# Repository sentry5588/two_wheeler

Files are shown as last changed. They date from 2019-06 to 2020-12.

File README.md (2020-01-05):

# Why Another Self-Balancing Robot?
Building a physical platform to test and compare various control and estimation algorithms. Almost all existing self-balancing robot uses PID control. I plan to use other control schemes with different robot state estimation methods.

# External Libs
LinkedList - Used for debug code communication
https://github.com/ivanseidel/LinkedList

ArduinoTimer - Used for timer interrupt
https://github.com/carlosrafaelgn/ArduinoTimer

# Note
I decided to use ROS on Raspberry PI instead of Arduino for the robot.

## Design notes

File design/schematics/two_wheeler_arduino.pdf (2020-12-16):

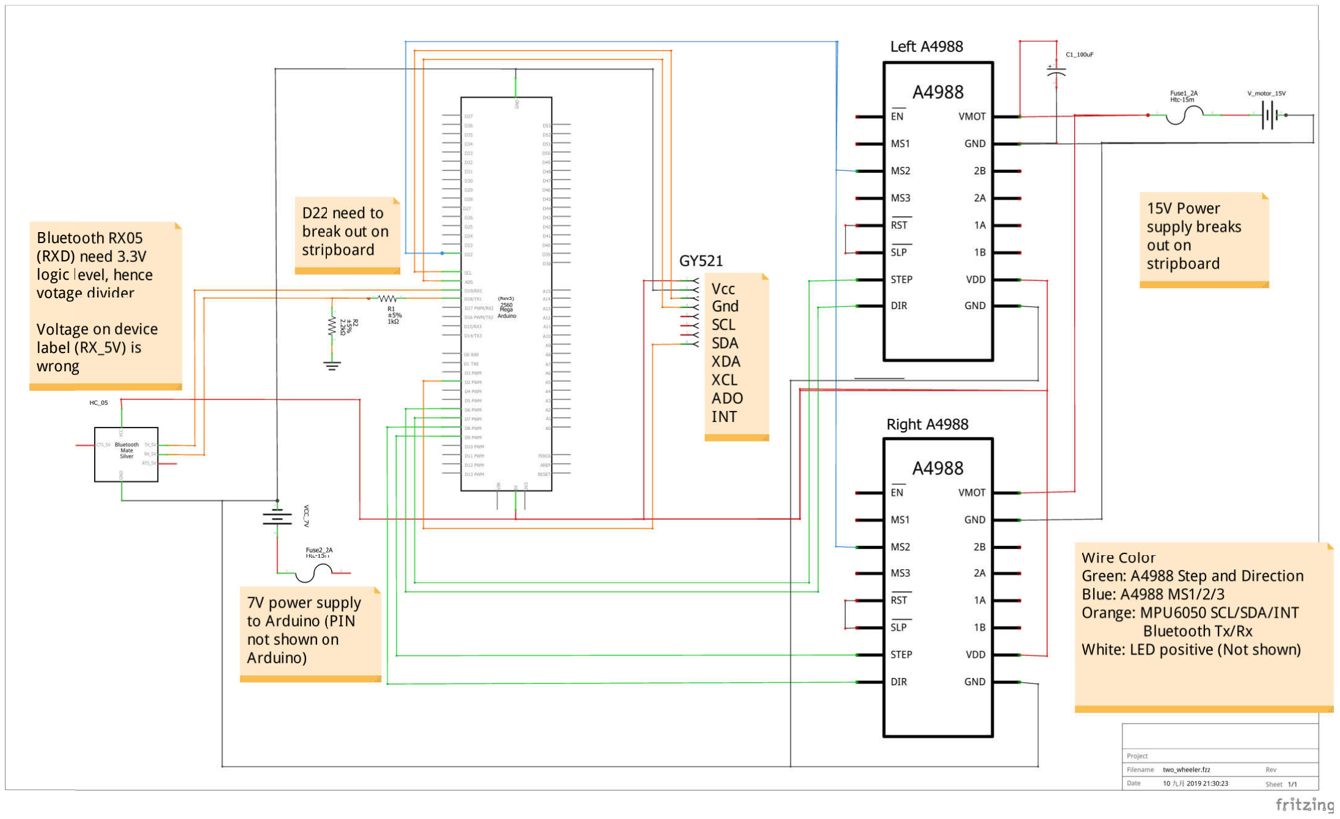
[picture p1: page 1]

Bluetooth RX05
(RXD) need 3.3V
logic level, hence
votage divider

Voltage on device
label (RX_5V) is
wrong

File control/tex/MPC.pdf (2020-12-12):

# Model Predictive Control

### sentry5588, MIT License

2020

## 1 Introduction

This note documents the Model Predictive Control (MPC) method for the two wheel balancing robot. Many people has built similar self-balancing robots. Almost all of them uses PID control as the control strategy. For position estimation, some uses Kalman filters, and others uses complementary filters. The purpose of using MPC in this robot is not trying to invent a new MPC technique, which usually the case for research papers. But rather I intend to 1) practice MPC and 2) test how well MPC behaves compares to other control schemes.

## 2 Robot Coordinates

As shown in Figure 1a, θk and ωk denotes the angular position at time step k, respectively. Counter-clockwise rotation is positive. Angular acceleration is denoted by ω˙ k. uk is the horizontal force with positive to the right. Robot specifications can be found in Table 1

## 3 Problem Formulation

The model is a 1-input-2-output model.

xk+1 = f(xk, uk) | (1)
yk = C(xk)xk | (2)

xk = [θk ωk ω˙ k]

T
is the system state. Linearize Equ 1, we have
xk+1 = A(xk)xk + B(xk)uk | (3)
yk = C(xk)xk | (4)
Specification | Notation | Value
Center of Gravity (CoG) | h | ?? 0.2 m
Mass | m | ?? 1.1 kg
Moment of Inertia | I | ?? 0.8 kg · m²

Table 1: Robot specification

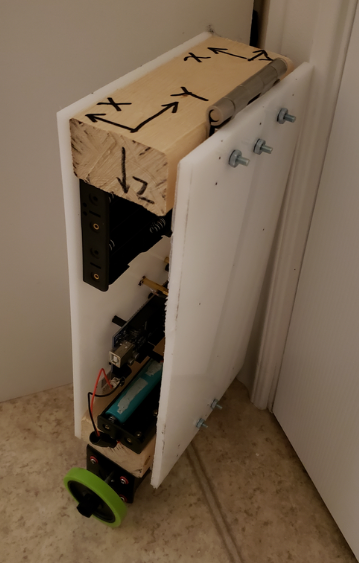
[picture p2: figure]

(a) Robot Coordinates

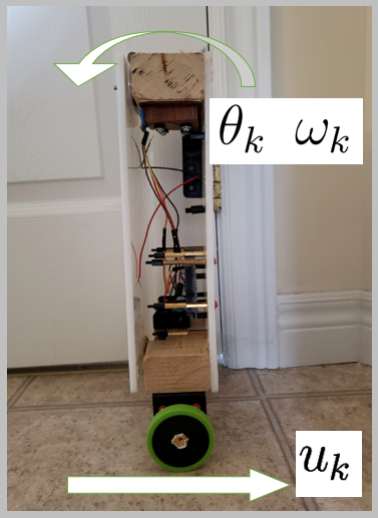
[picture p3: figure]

(b) 1D Rotation

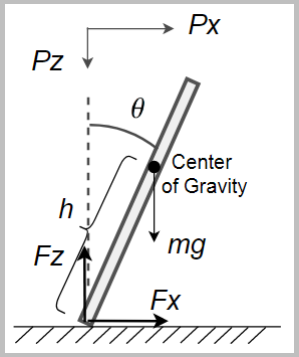
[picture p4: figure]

(c) 1D Free Dody Diagram

Figure 1: Two Wheel Balancing Robot

where A(xk) and B(xk) are Jacobians and given by

A(xk) = ∂f
∂xk

, B(xk) = ∂f
∂uk

(5)

Figure 1c is the 1-D free body diagram. In the next subsection, I will develop the nonlinear continuous-time dynamics.

### 3.1 Nonlinear Continuous-Time Model

### 3.1.1 Derived from Newton’s 2nd law

Summing the forces in figure 1c in the horizontal direction we have

Fx = mp¨x | (6)

where px is the horizontal velocity of the CoG. Summing the forces in figure 1c in the vertical direction we have

mg − Fz = mp¨z | (7)

where px is the horizontal velocity of the CoG. Summing the torques in figure 1c around the center of gravity we have

Fxh cos(θ) + Fzh sin(θ) + mg · 0 = ¨θI | (8)

The contact point between the robot and the ground has 0 vertical velocity. It’s vertical velocity is a combination of the rod rotation around CoG, ˙θh sin(θ), and vertical velocity of CoG, p˙z. Therefore

− ˙θh sin(θ) + ˙pz = 0 | (9)

Take time derivative of (9)

−¨θh sin(θ) − ˙θ
2h cos(θ) + ¨pz = 0 | (10)

p¨z = ¨θh sin(θ) + ˙θ
2h cos(θ) | (11)

Substitute p¨z in (7) with (11)

mg − Fz = m(

¨θh sin(θ) + ˙θ
2h cos(θ)) | (12)

mg − Fz = m¨θh sin(θ) + m ˙θ
2h cos(θ) | (13)

Fz = mg − m¨θh sin(θ) − m ˙θ
2h cos(θ) | (14)

Substitute Fz with above equation in (8)

Fxh cos(θ) + (mg − m¨θh sin(θ) − m ˙θ

2h cos(θ))h sin(θ) + mg · 0 = ¨θI | (15)

Fxh cos(θ) + mgh sin(θ) − m¨θh² sin²

(θ) − m ˙θ
2h

2

cos(θ) sin(θ) = ¨θI | (16)

(I + mh²

sin²

(θ))¨θ + mh²
cos(θ) sin(θ)

˙θ
2 = Fxh cos(θ) + mgh sin(θ) | (17)

So the dynamics can be written as

Fx = mp¨x | (18)

(I + mh²

sin²

(θ))¨θ + mh²
cos(θ) sin(θ)

˙θ
2 = Fxh cos(θ) + mgh sin(θ) | (19)

Check dynamics at special points for (19)
When θ = 0, i.e. the vertical up position, (19) becomes

I

¨θ = Fxh | (20)

When θ = π/2, i.e. the horizontal position pointing to the left (assume single contact point with the ground) (19) becomes

(I + mh²
)
¨θ = mgh | (21)

When θ = −π/2, i.e. the horizontal position pointing to the right (assume single contact point with the ground) (19) becomes

(I + mh²
)
¨θ = −mgh | (22)

When θ = π/4, i.e. the horizontal position pointing to the left (assume single contact point with the ground) (19) becomes

(I +

1
2

mh²
)

¨θ +

1
2

mh² ˙θ
2 =

√
2
2

Fxh +

√
2
2
mgh | (23)

### 3.1.2 Derived from Lagrangian mechanics

The derivation follows [Peacock and Hadjiconstantinou, 2007]. The Lagrangian is L = KE − P E where KE and P E are the kinematic energy and potential energy, respectively. W is the virtual work. The equation of motion can be determined by applying Lagrange mechanics in two generalized coordinate px and θ

d
dt

(
∂L
∂p˙x

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
∂θ =

∂W
∂θ | (24)

The contact point displacement relative to the center of gravity is hθ cos(θ). Therefore the absolute velocity of the contact point is px + hθ cos(θ). The kinematic energy, potential energy and virtual work are

KE =

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
, | P E = mgh cos(θ), | W = Fx(px + hθ cos(θ)) + Fxhθ cos(θ) = Fxpx + 2Fxhθ cos(θ)
(25)

Substitute (24) with (25), in px direction we have

| d dt

(
| ∂ ∂p˙x

(
| 1
| 2 mp˙
| 2 x + | 1
| | 2 I ˙θ
| | 2
)) | (26)

−

∂
∂px

(
| 1
| 2 mp˙
| 2 x +
| 1
| 2 I ˙θ
2 − mgh cos(θ)

)
| | = ∂ ∂px Fxpx + ∂ ∂px
2Fxhθ cos(θ) | (27)
| d dt
(mp˙x + 0) − (0 + 0 − 0) =Fx + 0 | (28)
| | d dt
mp˙x =Fx | (29)
mp¨x =Fx | (30)

Substitute (24) with (25), in θ direction we have

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
| mp˙
| 2 x +
| 1
| 2 I ˙θ
2 − mgh cos(θ)

)) −
| | ∂

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
2 − mgh cos(θ)

)
(31)

=

∂
∂θFxpx +

∂
∂θ 2Fxhθ cos(θ) | (32)

d
dt

(0 + I

˙θ − 0) − (0 + 0 + mgh sin(θ)) = − 2Fxhθ sin(θ) + 2Fxh cos(θ) | (33)

(0 + I

¨θ − 0) − (0 + 0 + mgh sin(θ)) = − 2Fxhθ sin(θ) + 2Fxh cos(θ) | (34)

I

¨θ − mgh sin(θ) = − 2Fxhθ sin(θ) + 2Fxh cos(θ) | (35)

I

¨θ =2Fxh cos(θ) + mgh sin(θ) − 2Fxhθ sin(θ) | (36)

### 3.2 Model Linearization and discretization

I follow [Zhakatayev et al., 2017] to linearize and discretize the nonlinear continuous-time dynamics in [?]

## References

[Peacock and Hadjiconstantinou, 2007] Peacock, T. and Hadjiconstantinou, N. (2007). Dynamics and control i. MIT OpenCourseWare.

[Zhakatayev et al., 2017] Zhakatayev, A., Rakhim, B., Adiyatov, O., Baimyshev, A., and Varol, H. A. (2017). Successive linearization based model predictive control of variable stiffness actuated robots. In 2017 IEEE International Conference on Advanced Intelligent Mechatronics (AIM), pages 1774– 1779. IEEE.

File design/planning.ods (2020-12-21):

Task | Hrs
Create arduino code – a4988 drive | 10
Arduino code – rpi connection | 5
rpi code – arduino connection | 5
schematics | 2
arduino mouting | 4
Arduino – a4988 wiring | 1
Rpi – arduino wiring | 1
max speed | 5 | rav/s
step Hz | 4000 | Hz

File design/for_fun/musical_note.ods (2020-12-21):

Note | Freq (Hz) | Left Motor PWM Freq
1 | 262 |  | 1 | 262
1.5 | 277
2 | 294 |  | 2 | 294
2.5 | 311
3 | 330 |  | 3 | 330
4 | 349 |  | 4 | 349
4.5 | 370
5 | 392 |  | 5 | 392
5.5 | 415
6 | 440 |  | 6 | 440
6.5 | 466
7 | 494 |  | 7 | 494
1 | 523 |  | 1 | 523
1.5 | 554
2 | 587 |  | 2 | 587
2.5 | 622
3 | 659 |  | 3 | 659
4 | 698 |  | 4 | 698
4.5 | 740
5 | 784 |  | 5 | 784
5.5 | 831
6 | 880 |  | 6 | 880
6.5 | 932
7 | 988 |  | 7 | 988
1 | 1047
1.5 | 1109
2 | 1175
2.5 | 1245
3 | 1319
4 | 1397
4.5 | 1480
5 | 1568
5.5 | 1661
6 | 1760
6.5 | 1865
7 | 1976

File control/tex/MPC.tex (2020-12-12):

\documentclass[12pt]{article}
\usepackage{amsmath}
\usepackage{graphicx}
\usepackage{hyperref}
\usepackage{xcolor}
\usepackage{subcaption}
\usepackage{siunitx}

\addtolength{\oddsidemargin}{-.875in}
\addtolength{\evensidemargin}{-.875in}
\addtolength{\textwidth}{1.75in}

\addtolength{\topmargin}{-.875in}
\addtolength{\textheight}{1.75in}

\title{Model Predictive Control}
\date{2020}
\author{sentry5588, MIT License}

\begin{document}
\pagecolor{lightgray}
\maketitle
\section{Introduction}
This note documents the Model Predictive Control (MPC) method for the two
wheel balancing robot. Many people has built similar self-balancing robots.
Almost all of them uses PID control as the control strategy. For position
estimation, some uses Kalman filters, and others uses complementary filters.

The purpose of using MPC in this robot is not trying to invent a new MPC
technique, which usually the case for research papers.
But rather I intend to 1) practice MPC and 2) test how well MPC behaves
compares to other control schemes.

\section{Robot Coordinates}
As shown in Figure~\ref{fig_coordinates}, $\theta_k$ and $\omega_k$ denotes 
the angular position at time step $k$, respectively.
Counter-clockwise rotation is positive. Angular acceleration is denoted
by $\dot{\omega}_k$.
$u_k$ is the horizontal force
with positive to the right. Robot specifications can be found in 
Table~\ref{tab_robot_specification}

\begin{figure}

\begin{subfigure}{0.3\textwidth}

\caption{Robot Coordinates} \label{fig_coordinates}
\end{subfigure}
\hspace*{\fill} % separation between the subfigures
\begin{subfigure}{0.3\textwidth}
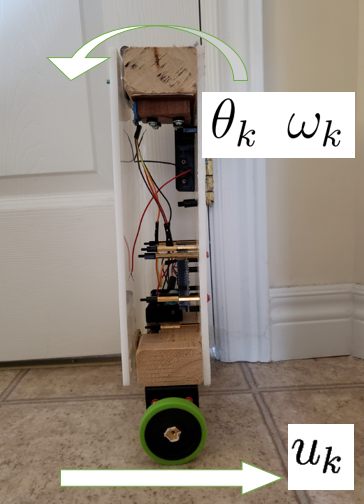
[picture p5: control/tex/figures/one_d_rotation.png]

\caption{1D Rotation} \label{fig_one_d_rotation}
\end{subfigure}
\hspace*{\fill} % separation between the subfigures
\begin{subfigure}{0.3\textwidth}
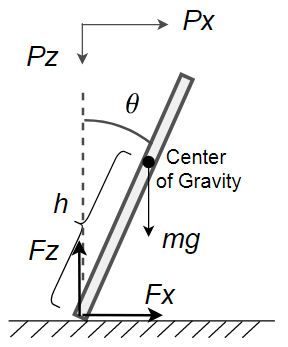
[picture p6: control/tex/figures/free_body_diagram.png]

\caption{1D Free Body Diagram} \label{fig_1d_free_body_diagram}
\end{subfigure}
\caption{Two Wheel Balancing Robot} \label{fig_robots}
\end{figure}

\begin{table}
  \centering
  \begin{tabular}{l|c|c}
    \hline
	Specification & Notation & Value \\ \hline
    Center of Gravity (CoG) & $h$ & ?? 0.2 m \\ 
	Mass & $m$ & ?? 1.1 kg \\ 
	Moment of Inertia & I & ?? 0.8 \si{\kilogram\cdot\meter^2} \\ \hline
  \end{tabular}
  \caption{Robot specification} 
  \label{tab_robot_specification}
\end{table}

\section{Problem Formulation}
The model is a 1-input-2-output model.
\begin{align}
\label{equ_orig_nonlinear_dynamics}
x_{k+1} & = f(x_k, u_k) \\
y_k & = C(x_k)x_k
\end{align}

$x_k=[\theta_k\;\;\omega_k\;\;\dot{\omega}_k]^T$ is the system state. 
Linearize Equ~\ref{equ_orig_nonlinear_dynamics}, we have
\begin{align}
x_{k+1} & = A(x_k)x_k + B(x_k)u_k \\
y_k & = C(x_k)x_k
\end{align}

where $A(x_k)$ and $B(x_k)$ are Jacobians and given by
\begin{align}
A(x_k) = \frac{\partial f}{\partial x_k},
B(x_k) = \frac{\partial f}{\partial u_k}
\end{align}

Figure~\ref{fig_1d_free_body_diagram} is the 1-D free body diagram.
In the next subsection, I will develop the nonlinear continuous-time
dynamics.

\subsection{Nonlinear Continuous-Time Model}
\subsubsection{Derived from Newton's 2nd law}
Summing the forces in figure~\ref{fig_1d_free_body_diagram} in the horizontal
direction we have
\begin{align}
F_x=m\ddot{p}_x
\end{align}
where $p_x$ is the horizontal velocity of the CoG.
Summing the forces in figure~\ref{fig_1d_free_body_diagram} in the vertical
direction we have
\begin{align}
mg-F_z = m\ddot{p}_z
\label{equ_vertical_newton}
\end{align}
where $p_x$ is the horizontal velocity of the CoG.
Summing the torques in figure~\ref{fig_1d_free_body_diagram} around the
center of gravity we have
\begin{align}
F_x h\cos(\theta) + F_z h\sin(\theta) + mg\cdot 0= \ddot{\theta}I
\label{equ_rotation_newton}
\end{align}
\textcolor{blue}{
The contact point between the robot and the ground has $0$ vertical velocity.
It's vertical velocity is a combination of the rod rotation around 
CoG, $\dot{\theta}h\sin(\theta)$,
and vertical velocity of CoG, $\dot{p}_z$. Therefore
\begin{align}
-\dot{\theta}h\sin(\theta) + \dot{p}_z = 0
\label{equ_velocity_equation}
\end{align}
Take time derivative of~(\ref{equ_velocity_equation})
\begin{align}
-\ddot{\theta}h\sin(\theta) - \dot{\theta}^2h\cos(\theta) + \ddot{p}_z = 0\\
\ddot{p}_z = \ddot{\theta}h\sin(\theta) + \dot{\theta}^2h\cos(\theta)
\label{equ_ddot_p_z}
\end{align}}
Substitute $\ddot{p}_z$ in~(\ref{equ_vertical_newton}) 
with~(\ref{equ_ddot_p_z})
\begin{align}
mg-F_z = m(\ddot{\theta}h\sin(\theta) + \dot{\theta}^2h\cos(\theta)) \\
mg-F_z = m\ddot{\theta}h\sin(\theta) + m\dot{\theta}^2h\cos(\theta) \\
F_z = mg - m\ddot{\theta}h\sin(\theta) - m\dot{\theta}^2h\cos(\theta)
\end{align}
Substitute $F_z$ with above equation in~(\ref{equ_rotation_newton})
\begin{align}
F_xh\cos(\theta) + (mg - m\ddot{\theta}h\sin(\theta) 
- m\dot{\theta}^2h\cos(\theta))h\sin(\theta) + mg\cdot 0= \ddot{\theta}I\\
F_xh\cos(\theta) + mgh\sin(\theta) - m\ddot{\theta}h^2\sin^2(\theta) 
- m\dot{\theta}^2h^2\cos(\theta)\sin(\theta) = \ddot{\theta}I \\
(I+mh^2\sin^2(\theta))\ddot{\theta}+mh^2\cos(\theta)\sin(\theta)\dot{\theta}^2
=F_xh\cos(\theta) + mgh\sin(\theta)
\end{align}

So the dynamics can be written as 
\begin{align}
F_x &= m\ddot{p}_x \\
(I+mh^2\sin^2(\theta))\ddot{\theta}+mh^2\cos(\theta)\sin(\theta)\dot{\theta}^2
&= F_xh\cos(\theta) + mgh\sin(\theta)
\label{equ_nonlinear_CT_dynamics}
\end{align}

\textbf{Check dynamics at special points 
for~(\ref{equ_nonlinear_CT_dynamics})}

When $\theta=0$, i.e. the vertical up position,
(\ref{equ_nonlinear_CT_dynamics}) becomes
\begin{align}
I\ddot{\theta} = F_xh
\end{align}
When $\theta=\pi/2$, i.e. the horizontal position pointing to the left
(assume single contact point with the ground)
(\ref{equ_nonlinear_CT_dynamics}) becomes
\begin{align}
(I+mh^2)\ddot{\theta} = mgh
\end{align}
When $\theta=-\pi/2$, i.e. the horizontal position pointing to the right
(assume single contact point with the ground)
(\ref{equ_nonlinear_CT_dynamics}) becomes
\begin{align}
(I+mh^2)\ddot{\theta} = -mgh
\end{align}
When $\theta=\pi/4$, i.e. the horizontal position pointing to the left
(assume single contact point with the ground)
(\ref{equ_nonlinear_CT_dynamics}) becomes
\begin{align}
(I+\frac{1}{2}mh^2)\ddot{\theta}+\frac{1}{2}mh^2\dot{\theta}^2
&= \frac{\sqrt{2}}{2}F_xh + \frac{\sqrt{2}}{2}mgh
\end{align}

\subsubsection{Derived from Lagrangian mechanics}
The derivation follows~\cite{peacock_2007_mit_lagrange}.
The Lagrangian is $L=KE-PE$ where $KE$ and $PE$ are the
kinematic energy and potential energy, respectively.
$W$ is the virtual work.
The equation of motion can be determined by applying
Lagrange mechanics in two generalized coordinate $p_x$ and $\theta$
\begin{align}
\label{equ_lagrangian_original}
\frac{\mathrm{d}}{\mathrm{d}t}\bigg(
\frac{\partial L}{\partial \dot{p}_x}\bigg)
-\frac{\partial L}{\partial p_x}=
\frac{\partial W}{\partial p_x}, \quad
\frac{\mathrm{d}}{\mathrm{d}t}\bigg(
\frac{\partial L}{\partial \dot{\theta}}\bigg)
-\frac{\partial L}{\partial \theta}=
\frac{\partial W}{\partial \theta}
\end{align}
The contact point displacement relative to the center of gravity is
$h\theta \cos(\theta)$. Therefore the absolute velocity of
the contact point is $p_x + h\theta \cos(\theta)$.
The kinematic energy, potential energy and virtual work are
\begin{align}
KE = \frac{1}{2}m\dot{p}_x^2
+\frac{1}{2}I\dot{\theta}^2,\quad
PE = mgh\cos(\theta), \quad
W = F_x (p_x+ h\theta \cos(\theta)) + F_x h \theta \cos(\theta)
= F_x p_x + 2F_x h \theta \cos(\theta)
\label{equ_lagrangian_energy_work}
\end{align}
Substitute~(\ref{equ_lagrangian_original})
with~(\ref{equ_lagrangian_energy_work}), in $p_x$ direction we have
\begin{align}
\frac{\mathrm{d}}{\mathrm{d}t}\bigg(
\frac{\partial}{\partial \dot{p}_x}\bigg(
\frac{1}{2}m\dot{p}_x^2 + \frac{1}{2}I\dot{\theta}^2\bigg)\bigg) \quad &\\
-\frac{\partial}{\partial p_x}\bigg(
\frac{1}{2}m\dot{p}_x^2+\frac{1}{2}I\dot{\theta}^2
-mgh\cos(\theta)\bigg)=&
\frac{\partial}{\partial p_x}F_x p_x
+\frac{\partial}{\partial p_x} 2F_x h \theta \cos(\theta) \\
\frac{\mathrm{d}}{\mathrm{d}t}
(m\dot{p}_x + 0)
-(0+0-0)=&
F_x + 0\\
\frac{\mathrm{d}}{\mathrm{d}t}
m\dot{p}_x = & F_x \\
m\ddot{p}_x =& F_x
\end{align}
Substitute~(\ref{equ_lagrangian_original})
with~(\ref{equ_lagrangian_energy_work}), in $\theta$ direction we have
\begin{align}
&\frac{\mathrm{d}}{\mathrm{d}t}\bigg(
\frac{\partial}{\partial\dot{\theta}}\bigg(
\frac{1}{2}m\dot{p}_x^2+\frac{1}{2}I\dot{\theta}^2
-mgh\cos(\theta)\bigg)\bigg)
-\frac{\partial}{\partial \theta}\bigg(
\frac{1}{2}m\dot{p}_x^2+\frac{1}{2}I\dot{\theta}^2
-mgh\cos(\theta)\bigg)  \\
=&\frac{\partial}{\partial \theta}F_x p_x
+\frac{\partial}{\partial \theta} 2F_x h \theta \cos(\theta) 
\end{align}
\begin{align}
\frac{\mathrm{d}}{\mathrm{d}t}
(0+I\dot{\theta}-0)
-(0+0+mgh\sin(\theta))=&-2 F_x h\theta \sin(\theta)
+2F_x h\cos(\theta)\\
(0+I\ddot{\theta}-0)
-(0+0+mgh\sin(\theta))=& -2 F_x h\theta \sin(\theta)
+2F_x h\cos(\theta) \\
I\ddot{\theta}-mgh\sin(\theta)=&-2 F_x h\theta \sin(\theta)
+2F_x h\cos(\theta) \\
I\ddot{\theta}
=& 2 F_x h\cos(\theta)+mgh\sin(\theta)
-2 F_x h\theta \sin(\theta)
\end{align}

\subsection{Model Linearization and discretization}
I follow~\cite{zhakatayev_2017_successive_linearize_MPC}
to linearize and discretize the nonlinear continuous-time dynamics
in~\cite{???}

%%%%%%%%%%%%%%%%%%%%%%%%%%%%%%%%%%%%%%%%%%%%%%%%
\bibliographystyle{apalike}
\bibliography{MPC}{}

\end{document}
%
%
%
%
%
%
%
%
%
%
%
%
%
%
%
%

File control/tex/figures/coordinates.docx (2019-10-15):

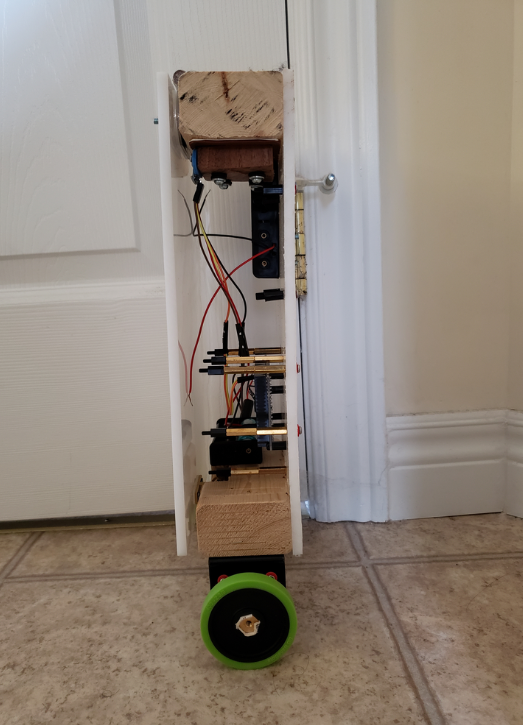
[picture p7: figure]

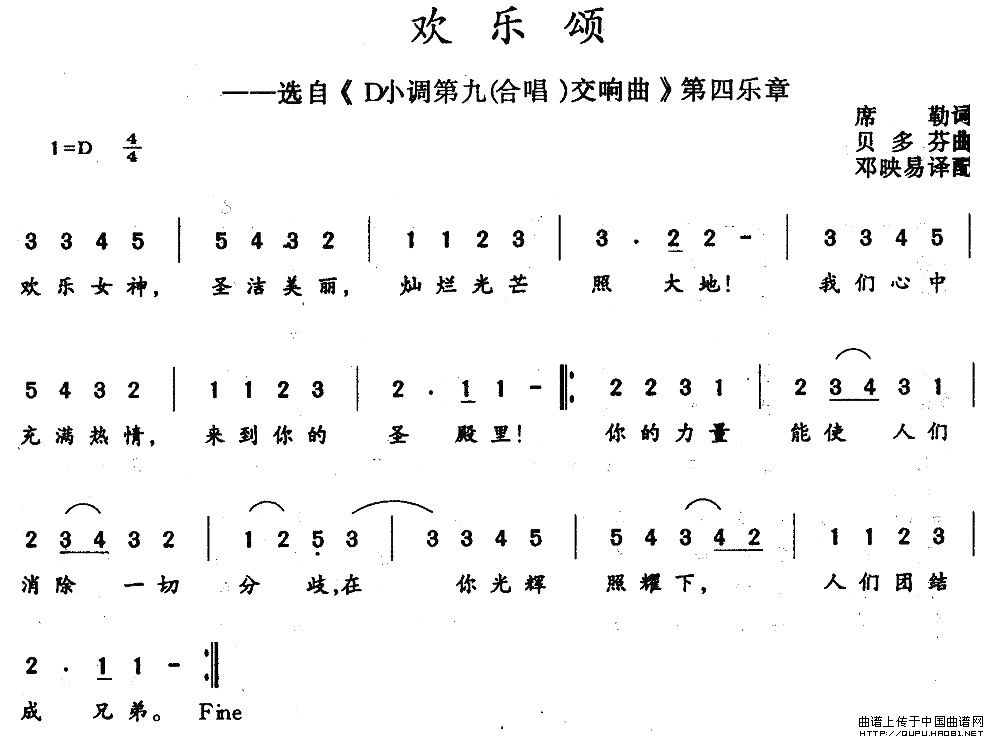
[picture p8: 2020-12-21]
design/for_fun/ode_of_joy.jpeg

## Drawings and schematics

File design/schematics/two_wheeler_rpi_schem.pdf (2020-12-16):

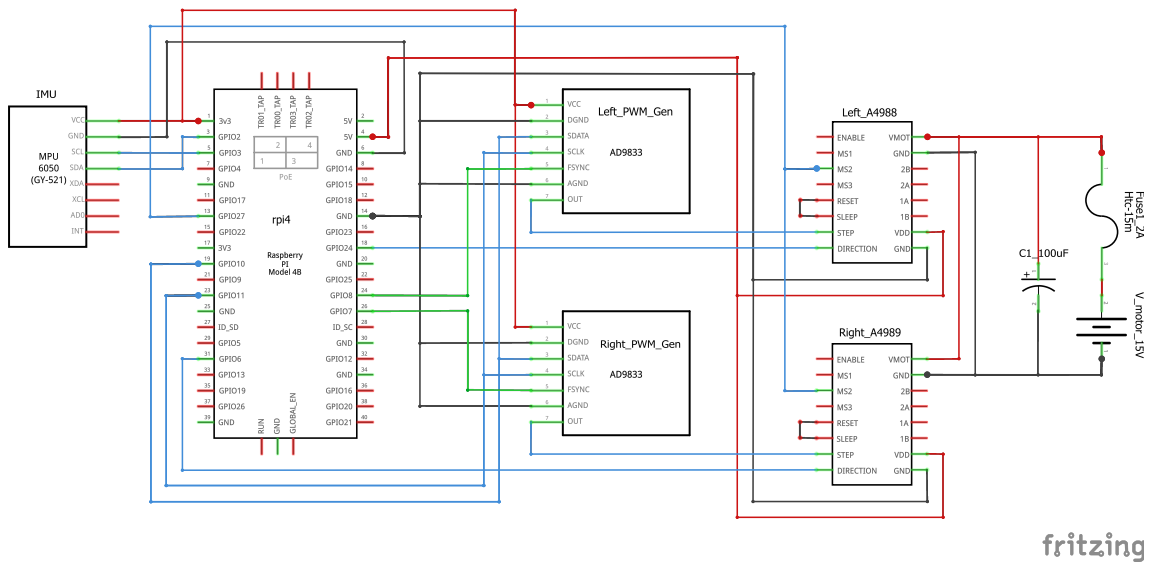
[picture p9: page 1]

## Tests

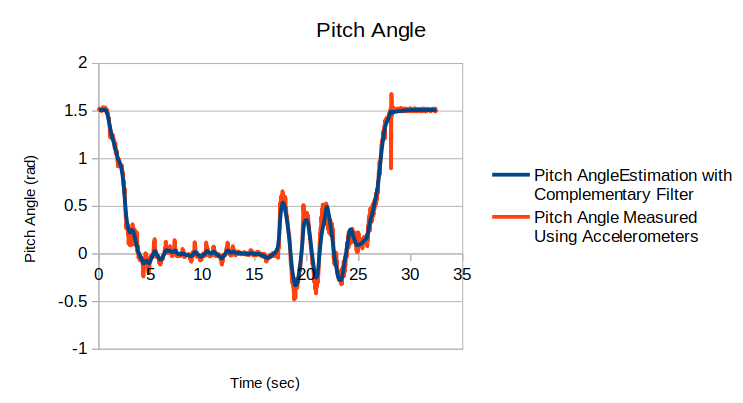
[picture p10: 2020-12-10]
analysis/complementary_filter_result.png

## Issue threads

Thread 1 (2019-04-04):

In sensor branch, visualization drift off as time passes by

sentry5588, 2019-04-04:
Arduino sends estimated angular positions (x, y, z) on board. To verify the estimation algorithm, a python script is created to visualize the robot position using PyOpenGL module. The display works fine initially. However, after a few rotations, it displays a tilted object even Arduino is sending (x=0, y=0, z=0) to python.

This issue is to due to how the rotation is done in python. It first differentiates the position (x, y, z) into (dx, dy, dz). Then rotate the object by (dx, dy, dz) in each time step. Due to round errors, the display cannot restore to original position when (x=0, y=0, z=0).

Possible solutions 1) reset the display 2) rotate the object back after each rotation. I have not find the function/method for resetting the display. Rotating the object back sounds strange.

sentry5588, 2019-04-04:
With commit 67acfeb, this issue is fixed.

Closed 2019-04-04.

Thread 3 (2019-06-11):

Replace "digitalWrite" with bit-wise operation

sentry5588, 2019-06-11:
"digitalWrite" is slow. To save computation power, replace it with bit-wise operation.

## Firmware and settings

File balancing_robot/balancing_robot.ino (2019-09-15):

/*
   The main program for controlling the self-balancing robot
   Created by sentry5588, Apr 2019
   MIT License
*/
#include <Wire.h>
#include <LinkedList.h>
#include <Timer5.h>
#include "global.h"
#include "MPU6050.h"
#include "Motor.h"
#include "Comm.h"

const int MPU = 0x68; // The address for MPU6050 when AD0 is not set
const unsigned int Wheel_Dir_Pin_L = 6;  // Direction for left wheel
const unsigned int Wheel_Step_Pin_L = 7; // Step for left wheel
const unsigned int Wheel_Dir_Pin_R = 8;  // Direction for right wheel
const unsigned int Wheel_Step_Pin_R = 9; // Step for right wheel
unsigned long debug_microstep_count = 0;

unsigned long previous_millis = 0;
unsigned long this_time_step = 0;
const long loop_time_step = 10; // milli-second (ms)
unsigned int serial_comm_i = 0;  // counter for serial communication

// instantiation of MPU6050 for position and velocity
// using offset values obtained for my particular chip
MPU6050 pv_sensor(double(16829.29), double(85.0909), double(-2744.00),
                  double(477.0), double(124.0), double(182.0));
// Instantiation of left stepper motor and right stepper motor
Motor lm(Wheel_Dir_Pin_L, Wheel_Step_Pin_L); // lm: left motor;
Motor rm(Wheel_Dir_Pin_L, Wheel_Step_Pin_L); // rm: right motor

// instantiation of debug list
Comm send_debug(uint8_t(1));

// To do: move sensor address and comm setup into sensor class definition
void setup() { // setup communication
  Wire.begin();
  Wire.beginTransmission(MPU);
  Wire.write(0x6B);
  Wire.write(0);
  Wire.endTransmission(true);
  Serial.begin(115200); // baud rate of 9600 is too slow

  // Setup motor pins as Outputs
  pinMode(Wheel_Dir_Pin_L, OUTPUT);
  pinMode(Wheel_Step_Pin_L, OUTPUT);
  pinMode(Wheel_Dir_Pin_R, OUTPUT);
  pinMode(Wheel_Step_Pin_R, OUTPUT);

  // To be deleted once a jumper wire is found
  pinMode(22, OUTPUT);
  pinMode(23, OUTPUT);
  pinMode(24, OUTPUT);
  digitalWrite(22, LOW);
  digitalWrite(23, HIGH);
  digitalWrite(24, LOW);

  // Setup timer trigger interval (us)
  startTimer5(500L);
}

void loop() {
  // declare current time and time step from last execution
  unsigned long current_millis = millis();
  // calc how many ms passed since last time the code was ran
  this_time_step = current_millis - previous_millis;
  // Main control loop
  if (this_time_step >= loop_time_step) { // if longer than the time step
    previous_millis = current_millis; // save the last time the code ran

    // Sensor data reading, processing and state estimation ======================
    pv_sensor.sensor_read(MPU); // read sensor raw data
    pv_sensor.gyro_corr_offset(); // correct sensor offset
    pv_sensor.state_est_AO(this_time_step); // use AO to estimate robot states
    pv_sensor.state_est_GOSI(this_time_step); // use GOSI to estimate robot states
    pv_sensor.state_est_CF(this_time_step); // use GOSI to estimate robot states

    // Compute controller output using different control algorithms ==============
    // To do

    // Send controller output to actuators =======================================
    //    lm.set_speed(4.0, bool(FORWARD), loop_time_step);

    // Control debug: 1) live value display, 2) data log, 3) troubleshooting ====
    // Reset CPU idle time indicator
    debug_data_manage(current_millis);
    send_debug.scheduled_send();
    debug_list.clear();
    idle_loop_count = 0; // Reset CPU idle time indicator
  } else {
    idle_loop_count++; // Increase CPU idle time counter by 1
  } // if (this_time_step >= loop_time_step) { // if longer than the time step
} // void loop(){

void debug_data_manage(unsigned long current_millis) {
  // Try to limit the data via serial, it's slow. It'll limit loop time
  debug_list.add(double(this_time_step));
  debug_list.add(double(idle_loop_count));
  //  debug_list.add(s_GOSI[0]);
  //  debug_list.add(s_GOSI[1]);
  //  debug_list.add(s_GOSI[2]);
  debug_list.add(s_AO[0]);
  debug_list.add(s_AO[1]);
  debug_list.add(s_AO[2]);
  //  debug_list.add(s_CF[0]);
  //  debug_list.add(s_CF[1]);
  //  debug_list.add(s_CF[2]);
}

ISR(timer5Event) {
  resetTimer5();
  //  digitalWrite(Wheel_Step_Pin_L, HIGH);
  //  digitalWrite(Wheel_Step_Pin_L, LOW);
  if (debug_microstep_count < 200 * 4) {
    PORTH |= _BV(PH4);
    PORTH &= ~_BV(PH4);
  }
  if (debug_microstep_count == 2000) {
    debug_microstep_count = 0;
  }
  debug_microstep_count ++;
}

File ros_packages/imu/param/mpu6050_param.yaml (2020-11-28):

angular_x_bias: 0.0
angular_x_scaling: 1.0
angular_y_bias: 0.0
angular_y_scaling: 1.0
angular_z_bias: 0.0
angular_z_scaling: 1.0

linear_x_accel_bias: 0.0
linear_x_accel_scaling: 1.0
linear_y_accel_bias: 0.0
linear_y_accel_scaling: 1.0
linear_z_accel_bias: 0.0
linear_z_accel_scaling: 1.0

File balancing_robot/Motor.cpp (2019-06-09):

#include <Wire.h>
#include "Motor.h"
#include "Arduino.h"
#include "global.h"

Motor::Motor(unsigned int Dir_Pin, unsigned int Step_Pin) {
  dir_pin = Dir_Pin;
  step_pin = Step_Pin; 
}

void Motor::set_speed(double omega, bool d, long dt) {
  // omega: required angular velocity (rad/s)
  // dt: controller cycle, in milli-second (ms)
  unsigned int s = 0; // run steps in one control cycle
  unsigned int s_period = 1200; // delay between motor steps (micro-second)
  s = int(double(dt) * 0.001 * omega / (2.0 * PI) * double(STEPS_PER_REV));
  debug_list.add(s);
  debug_list.add(double(dir_pin));
  debug_list.add(double(step_pin));
  debug_list.add(double(s_period));
  if (d == FORWARD){
    digitalWrite(dir_pin, HIGH);
  } else {
    digitalWrite(dir_pin, LOW);
  }

  for (int i = 0; i < s; i++) {
    digitalWrite(step_pin, HIGH);
    delayMicroseconds(s_period);
    digitalWrite(step_pin, LOW);
    delayMicroseconds(s_period);
  }
}

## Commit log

2019-04-02 Added MPU6050 (GY521) sensor read; it extracts raw gyro data from the sensor
2019-04-03 Reduced communication load for serial; WIP to create GOSI state estimation
    GOSI state estimation - Using gyro data to estimate the robot state by simply integrating the angular velocities.
2019-04-04 Created python script to visualize the robot position
    The python script using PyOpenGL module. After a few rotations, the position on display drift off from the data obtained from Arduino. This is an issue.
    [visulize_imu.py]
2019-04-04 Updated visualization python script to fix issue #1
    - Using glPushMatrix() and glPopMatrix() in PyOpenGL lib to restore the object back to the original position after any rotation. So next time, the "glRotatef" function can take angular positions (x, y, z) and directly rotate to from (0, 0, 0) to (x, y, z).
    - Added misc code comments
    [visulize_imu.py]
2019-04-15 Created MPU6050 class
    Created a sensor class for MPU6050. It reads sensor MPU6050 raw values, corrects offsets, and provides methods to estimate robot states. Future estimation methods will be included in this class.
2019-04-15 Created constructor method for class MPU6050
    Added class constructors by taking pre-determined gyro offset values. Deleted unused variables: x_total_deg = 0, y_total_deg = 0, z_total_deg = 0.
    .
2019-04-18 Created library for sensor, communication
    - Moved sensor class into library
    - Created communication library
    - Created global variable definition file
    - Renamed main Arduino file to "balancing_robot.ino"
    - Changed folder structure for python code
2019-04-18 Created Motor Class
    - Created motor class for controlling stepper motors
    - Created function to manage debug data list "debug_data_manage"
    - Revised Comm class to send data using linked list
    - Misc changes: comments, etc
2019-04-19 Fixed angular position estimation out of range
    Fixed bug: angular positions could go out of range
    [MPU6050.cpp, balancing_robot.ino]
2019-04-19 state_est_AO development in process
    In the process of developing MPU6050 method "state_est_AO". This method estimate robot state using accelerometer data only. (not completed)
2019-04-21 Work in progress - Implementing complementary filter
    Not complete
2019-04-22 Removed angular position range [0-360) correction
    The range correction is not necessary.
    [MPU6050.cpp]
2019-04-30 Created new method for calcing Euler angle
    - Redefined state variables
    - Added methods to calculate roll/pitch/yaw basd on accelerometer readings
2019-06-09 Motor Drive in progress
2019-06-13 Added "ArduinoTimer" in the External Libs section
2019-06-13 Changed motor drive using timer interrupt
    - Added new lib
    - Changed stepper motor driving from main loop to interrupt
    - Changed one "ditigalWrite" to port manipulation #3
2019-06-14 Selected initial motor microstepping parameters
    - Created jupyter note for determining stepper motor control parameters
    - After testing, stepper motor control interrupt selected as 0.5 ms. Stepper motor microstepping configured as 1/4. This allows linear travel resolutation <0.24mm and max linear travel speed > 0.47m/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
2020-11-28 Added imu config file
2020-12-04 Configured plotjoggler layout
    [wheel_speed_calc.ods]
2020-12-10 Added complementary filter results for pitch angle estimation
2020-12-16 Added schematics for both Arduino and RPI versions
    [two_wheeler_arduino.fzz, two_wheeler_rpi.fzz]
2020-12-17 Aligned component labels
    [two_wheeler_rpi_arduino.fzz]
2020-12-21 Merry Christmas - Added music note for fun
    [musical_note.ods, planning.ods]
